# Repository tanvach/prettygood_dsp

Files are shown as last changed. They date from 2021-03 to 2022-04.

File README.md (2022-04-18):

# Prettygood DSP

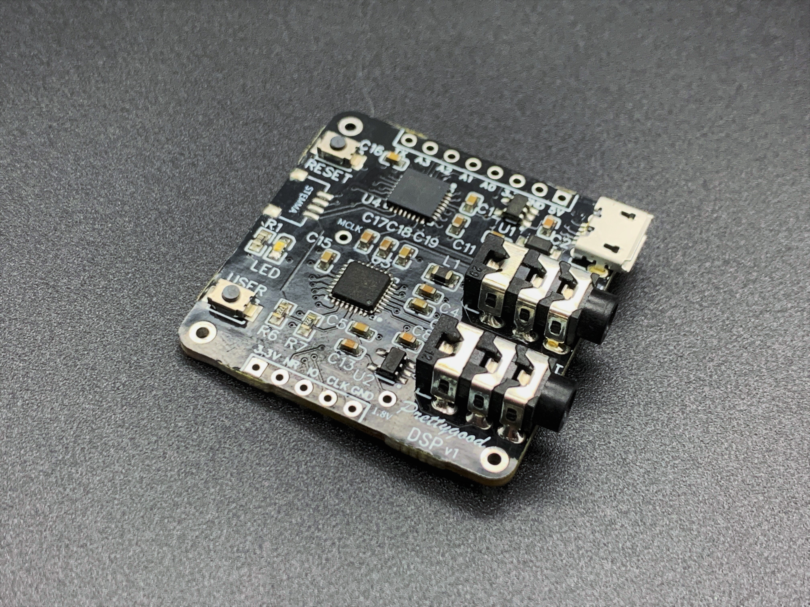
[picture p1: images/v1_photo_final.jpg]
board photo


A self contained, Arduino compatible board for applying audio DSP. The intended purpose is to equalize and apply bass boost to [BMR VR off ear headphones](https://prettygood3d.com/post/999028410814/quest-2-off-ear-bmr-v01), but can be adapted for any other light DSP tasks by SGTL5000 codec.

Supports:
-   7 band prarametric or 5 band graphic EQ.
-   AutoEQ profiles for 1000+ headphones and earbuds.
-   Psycho-acoustic bass boost to over come limited bass response of small headphone drivers.
-   Stereo surround expansion.
-   Automatic volume control.

Please see the SGTL5000 [documentation](https://www.pjrc.com/teensy/SGTL5000.pdf) for all DSP features. Credit to [Paul Stoffregen of PJRC.com](https://github.com/PaulStoffregen/Audio) for creating the Teensy Audio library (we're reusing a SGTL5000 component in the code).

TODO:
-   Make use of the USER button for switching between presets.

# Usage
- Plug in a USB power source. Anything from computer, phone, Quest/Quest 2 or some USB power bank (see below) should work.
- Plug in 3.5mm stereo jack from audio out to LINEIN.
- Plug your headphones into OUT.

NOTE: the OUT port is designed to drive headphones. It may not work as intended as an input into another audio device.

# WebUSB configurator
The latest version of the firmware allows you to config the DSP settings with Chrome browser through WebUSB.

To enter and use the WebUSB mode:
- Connect the board to your computer with a USB cable.
- Open a recent version of Chrome.
- Press and hold the *USER* button while pressing the *RESET* button.
- Release the *USER* button when the LED light turns off.
- Chrome should recorgnize the device as 'QT Py M0'.
- Click on the notification to go to the configuration page (https://tanvach.github.io/prettygood_dsp/).
- Click 'Connect' to pair and connect to the board (only needs to be done once).
- The LED light will turn on when WebUSB connection is established.

chrome notification

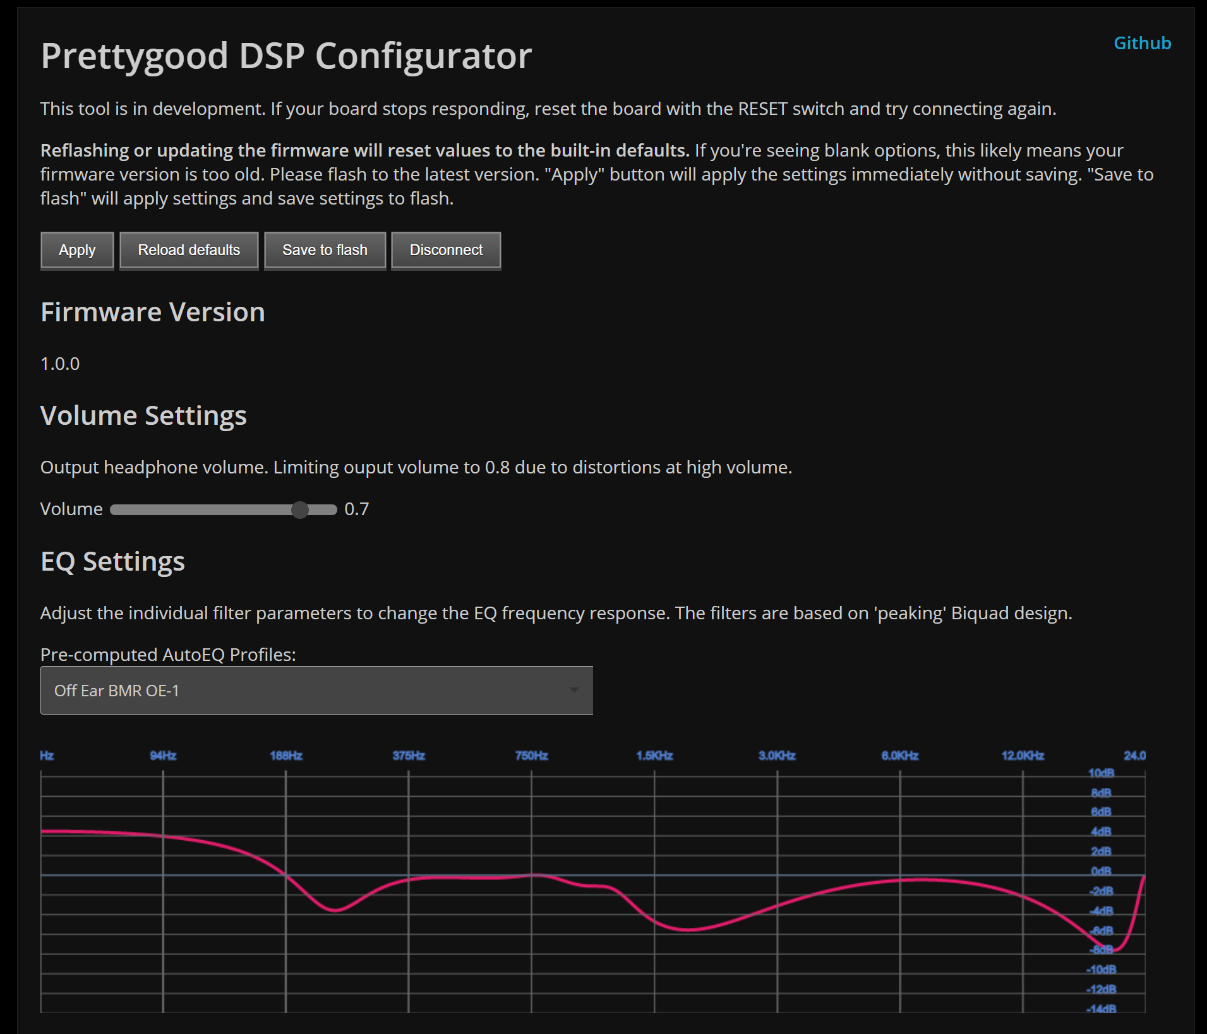
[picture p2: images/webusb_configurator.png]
webusb configurator


# USB Power Bank Compatibility
Most USB power banks will turn off when powering the board, since the current draw is too low.

- Some brands will allow 'low power draw' mode by holding the on button for few seconds (i.e. Xiaomi).
- A list of tested power banks that support low power draw https://www.candlepowerforums.com/vb/showthread.php?440476-USB-powerbank-WITHOUT-auto-off
- Use a USB splitter cable to power both the headset and DSP board (see below).
- Try using the 'Pulse USB Power' to periodically consume more power.

# Pulse USB Power
This feature will turn on the MCU DAC and periodically output max voltage to the A0 pin. This by itself consumes ~35mA of power. This is enough for some USB batteries to keep them awake. If not, you can conenct a short wire between A0 to GND to comsume even more power (~50mA). Adding this wire should be enough (tested with Anker branded batteries).

# USB Splitter Cable for Oculus Link
[This splitter cable](https://www.amazon.com/gp/product/B078MFCVLF/ref=ppx_yo_dt_b_asin_title_o00_s00?ie=UTF8&psc=1) is confirmed to work with Oculus Link and from power bank. It takes a Micro USB connection and split into USB-C (provides power and USB 2.0 data) and Micro USB (provides power only).

Alternatively, you can also [use this USB-C PD charging + USB-C headphone splitter](https://www.amazon.com/Splitter-HiMusic-Charging-Converter-Compatible/dp/B07MSLJ64X). The headphone port provides enough power to power the DSP. 

# Update firmware
The board firmare is updatable via USB.

- Connect the DSP board via USB and double clicking the RESET button. This triggers the boot loader mode.
- Check that the blue LED stays on and QTPY_BOOT drive is mounted on your desktop.
- Download 'firmware.uf2' file and copy it to the QTPY_BOOT drive. It should unmount automatically.
- The firmware update is complete. You can now disconnect the USB cable.

# Compile firmware
If you want to make changes to the firmware, you'd need to follow these steps.

*This board comes with a fail-safe bootloader mode, making it almost impossible to brick by updating the firmware through USB.*

## 1. Install Platform IO
You need to first install VSCode, then Platform IO by following [these instructions](https://platformio.org/install/ide?install=vscode).

## 2. Open in Platform IO
Download this repository using git clone command, or download and extract the zip file on your computer.

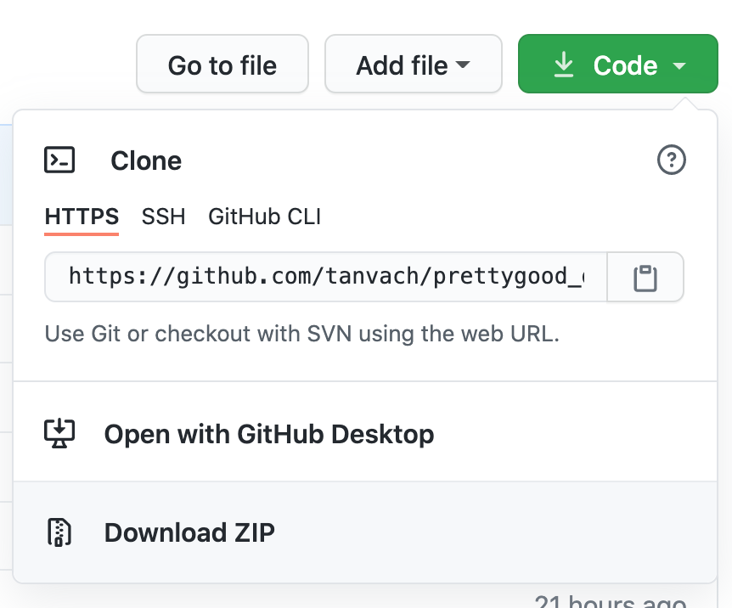
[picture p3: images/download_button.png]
download


In VSCode (with Platform IO installed), choose 'Open...' or 'Open Folder...' and select this repo's 'prettygood_dsp' folder.

## 3. Make changes and compile
Once you're happy making changes, select 'main.cpp' file and click the checkmark button at the bottom of VSCode to build the new firmware.

build

Platform IO will fetch all the dependencies automatically for you and compile the code. The file 'firmware.uf2' will be overwritten with the new version.

To upload the firmware, follow the 'Update firmware' section above.

## Dependencies
 - Adafruit Zero I2S
 - RTCZero
 - Adafruit TinyUSB Library
 - ArduinoJson
 - FlashStorage

# Board Design
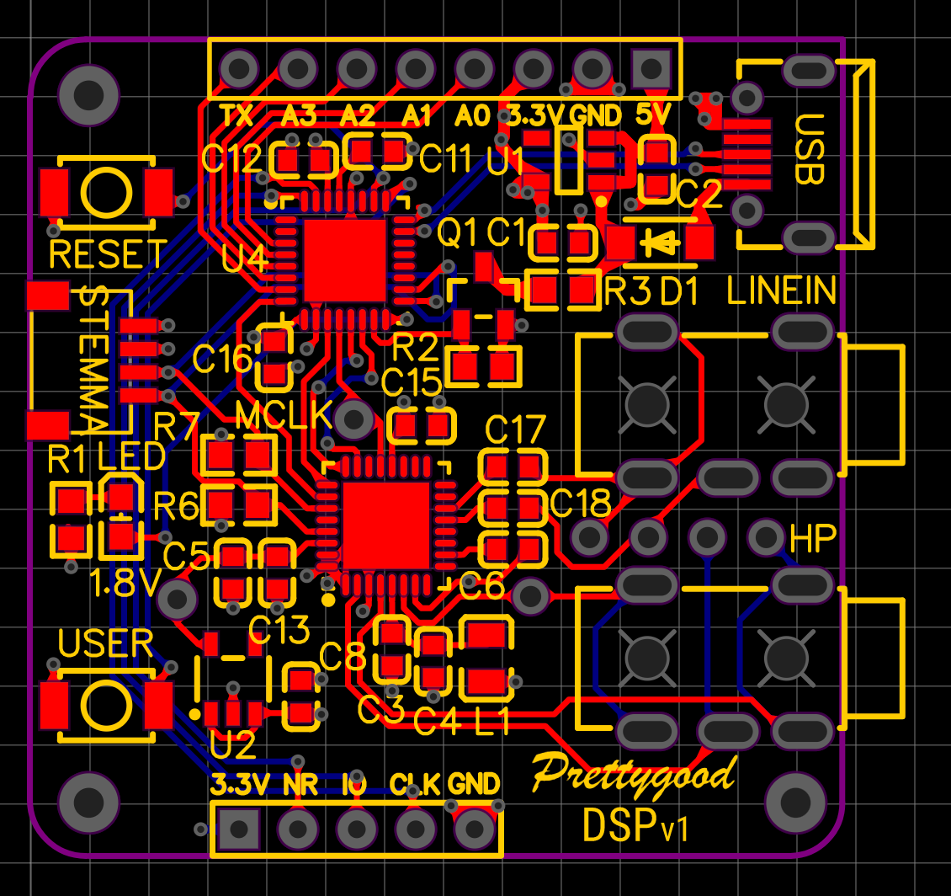
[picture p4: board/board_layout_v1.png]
Board Layout


The board is designed based on [Adafruit SAMD21 QtPy](https://learn.adafruit.com/adafruit-qt-py). The default bootloader is vanilla SAMD21 QtPy and can be download from [Adafruit SAMD UF2 repo](https://github.com/adafruit/uf2-samdx1/releases). The only difference is that we've replaced the NeoPixel with a blue LED.

The schematic can be found [here](board/schematic_v1.pdf).

The advantage of using this bootloader is that any projects that can run on SAMD21 boards (Aduino Zero, QtPy, Trinket M0, Feather M0) can theoretically run on Prettygood DSP.

One limitation - the I2S peripheral needs to be on to provide clock signals to the SGTL5000 codec. So the I2S/SPI pins are not available as GPIO. Otherwise the TX and A0-A3 pins are free and available.

# Contributing
Contributions are welcome!

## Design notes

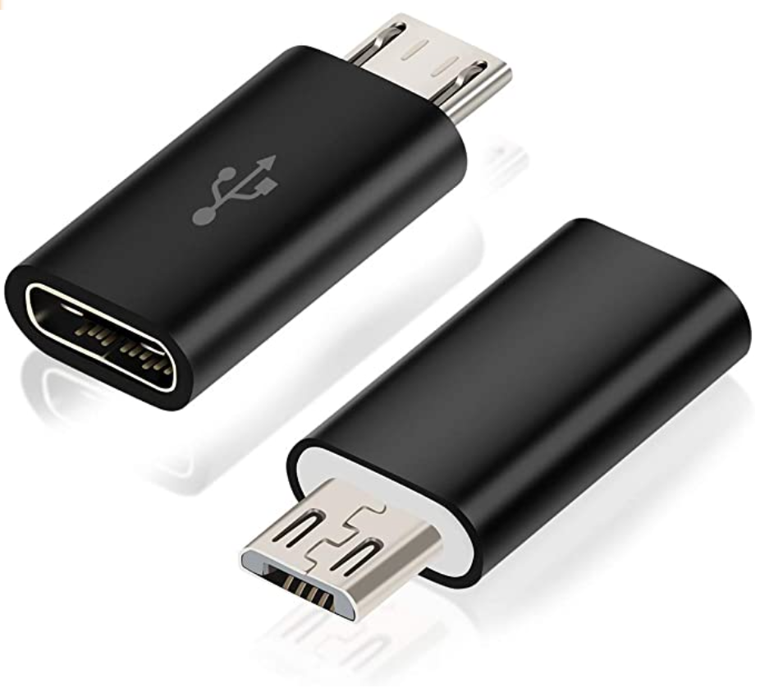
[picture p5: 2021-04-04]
images/usbc_to_micro.png

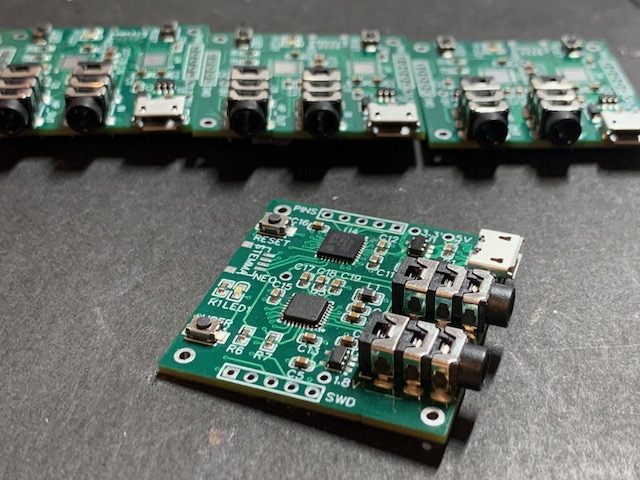
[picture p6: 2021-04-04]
images/v1_photo.jpeg

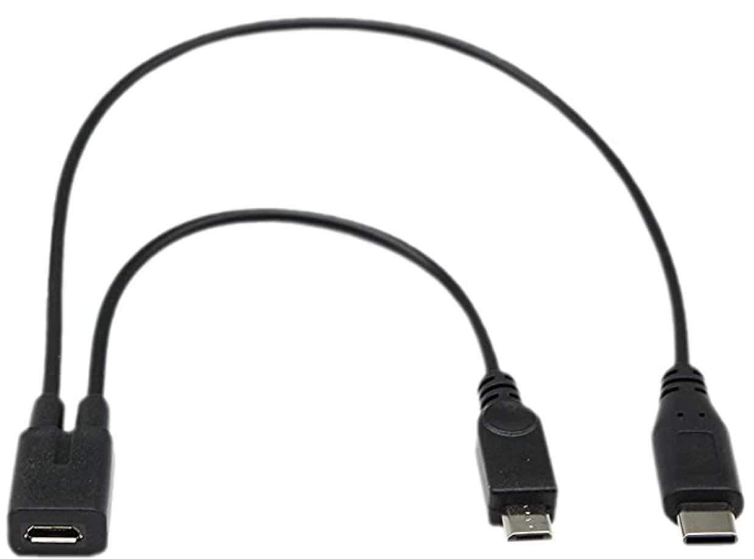
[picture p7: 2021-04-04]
images/micro_usb_splitter.png

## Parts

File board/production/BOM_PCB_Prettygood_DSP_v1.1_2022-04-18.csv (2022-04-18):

ID | Name | Designator | Footprint | Quantity | Manufacturer Part | Manufacturer | Supplier | Supplier Part | Price | Pins | 3DModel | Assembly Type | JLCPCB Part Class | JLCPCB SMD | LCSC Assembly | Paste Type | Contributor | Package Display | SMT Type | image | link | subpart_no
1 | B5819W | D1 | SOD-123_L2.8-W1.8-LS3.7-RD | 1 | B5819W | CJ | LCSC | C8598 | 0.039 | 2 | SOD-123_L2.8-W1.8-H1.4-LS3.7 | smtWeld |  | Yes | Yes | base | 官方封装库 |  | Basic | //image.lceda.cn/szlcsc/C8598.jpg | https://item.szlcsc.com/301422.html
2 | PJ-3930-8A | HP,IN | AUDIO-TH_PJ-3930-8A | 2 | PJ-3930-8A | HRO | LCSC | C145811 | 0.593 | 8 | AUDIO-TH_PJ-3930-8A |  | Extended Part |  |  |  | LCSC
3 | 150nF | C6 | C0603 | 1 | CL10B154KA8NNNC | SAMSUNG | LCSC | C21118 | 0.009 | 2 | C0603_L1.6-W0.8-H0.8 |  |  | Yes | Yes | expand | 立创EDA官方封装库 |  | Extend |  | https://item.szlcsc.com/362304.html
4 | 75 | R3 | R0603 | 1 | 0603WAF750JT5E | UniOhm | LCSC | C4275 | 0.001 | 2 | R0603_L1.6-W0.8-H0.8 |  |  | Yes | Yes | base | layout |  | Basic |  | https://item.szlcsc.com/137208.html
5 | 2N7002 | Q1 | SOT-23-3_L2.9-W1.3-P1.90-LS2.4-BR | 1 | 2N7002 | CJ | LCSC | C8545 | 0.023 | 3 | SOT-23-3P_L2.9-W1.3-H1.0-LS2.4-P0.95 |  |  | Yes | Yes | base | 立创EDA官方封装库 |  | Basic | //image.lceda.cn/szlcsc/C8545.jpg | https://item.szlcsc.com/9070.html
6 | 2.2K | R2,R6,R7 | R0603 | 3 | 0603WAF2201T5E | UniOhm | LCSC | C4190 | 0.001 | 2 | R0603_L1.6-W0.8-H0.8 | smtWeld |  | Yes | Yes | base | layout |  | Basic |  | https://item.szlcsc.com/137208.html
7 | NEO | MCLK | 1PIN | 1 | POINT |  |  | Do not populate |  | 1 |  |  |  |  |  |  | zydz
8 | 1.8V | 1.8V | 1PIN | 1 | POINT |  |  | Do not populate |  | 1 |  |  |  |  |  |  | zydz
9 | SGTL5000XNAA3 | U3 | QFN-32_L5.0-W5.0-P0.50-TL-EP3.7 | 1 | SGTL5000XNAA3 | NXP Semicon | LCSC | C511764 | 4.025 | 33 | QFN-32_L5.0-W5.0-H0.9-P0.50-TL-EP3.7 | smtWeld |  |  | Yes | expand | 官方封装库 |  | Extend |  | https://item.szlcsc.com/18002.html
10 | 2.2uF | C8,C5,C18,C17,C1,C2,C4 | C0603 | 7 | CL10A225KO8NNNC | SAMSUNG | LCSC | C23630 | 0.006 | 2 | C0603_L1.6-W0.8-H0.8 | smtWeld |  | Yes | Yes | base | 立创EDA官方封装库 |  | Basic |  | https://item.szlcsc.com/362304.html
11 | 600Ω | L1 | L0805 | 1 | CBW201209U601T | FH | LCSC | C21286 | 0.006 | 2 | L0805_L2.0-W1.6-H0.9 | smtWeld |  | Yes | Yes | expand | layout |  | Extend |  | https://item.szlcsc.com/344132.html
12 | ATSAMD21E18A-MU | U4 | QFN-32_L5.0-W5.0-P0.50-TL-EP | 1 | ATSAMD21E18A-MU | Microchip Tech | LCSC | C220692 | 2.795 | 33 | QFN-32_L5.0-W5.0-H1.0-P0.50-TL-EP | smtWeld |  | Yes | Yes | expand | 官方封装库 |  | Extend |  | https://item.szlcsc.com/18002.html
13 | AP2112K-3.3TRG1 | U1 | SOT-25-5_L3.0-W1.8-P0.95-LS3.0-BR | 1 | AP2112K-3.3TRG1 | DIODES | LCSC | C51118 | 1.49 | 5 | SOT-25-5_L3.0-W1.6-H1.3-LS2.8-P0.95 | smtWeld |  | Yes |  | recommend | LCSC |  | Extend |  | https://item.szlcsc.com/70677.html
14 | SWD | SWD | 1X5PIN | 1 |  |  |  | Do not populate |  | 5 |  |  |  |  |  |  | cmacarthur | No
15 | Pad | P1,P2,P3 | PAD | 3 |  |  |  | Do not populate |  | 1 |  |  |  |  |  |  | ericriss102 | No
16 | STEMMA_I2C_QT | STEMMA | JST_SH4 | 1 |  |  |  | Do not populate |  | 6 |  |  |  |  |  |  | wolf3x | No |  |  |  | 1
17 | ME6212C18M5G | U2 | SOT-23-5_L3.0-W1.7-P0.95-LS2.8-BL | 1 | ME6212C18M5G | Nanjing Micro One Elec | LCSC | C236669 | 0.05 | 5 | SOT-23-5_L2.9-W1.6-H1.1-LS2.8-P0.95 | smtWeld |  | Yes | Yes | expand | LCSC |  | Extend |  | https://item.szlcsc.com/236104.html
18 | 100nF | C3,C12,C13,C15,C16 | C0603 | 5 | CC0603KRX7R9BB104 | YAGEO | LCSC | C14663 | 0.002 | 2 | C0603_L1.6-W0.8-H0.8 | smtWeld |  | Yes | Yes | base | 立创EDA官方封装库 |  | Basic |  | https://item.szlcsc.com/362304.html
19 | 1uF | C11 | C0603 | 1 | CL10A105KB8NNNC | SAMSUNG | LCSC | C15849 | 0.005 | 2 | C0603_L1.6-W0.8-H0.8 | smtWeld |  | Yes | Yes | base | 立创EDA官方封装库 |  | Basic |  | https://item.szlcsc.com/362304.html
20 | 1K | R1 | R0603 | 1 | 0603WAF1001T5E | UniOhm | LCSC | C21190 | 0.001 | 2 | R0603_L1.6-W0.8-H0.8 | smtWeld |  | Yes | Yes | base | layout |  | Basic |  | https://item.szlcsc.com/137208.html
21 | MICROXNJ | USB | MICRO-USB-SMD_MICROXNJ | 1 | MicroXNJ | SHOU HAN | LCSC | C404969 | 0.046 | 9 | MICRO-USB-SMD_105017-0001 | smtWeld |  |  |  | expand | LCSC |  |  |  | https://item.szlcsc.com/392534.html
22 | 1x8 | PINS | HDR-8X1/2.54 | 1 |  |  |  | Do not populate |  | 8 |  |  |  |  |  |  |  | No
23 | TS-1088-AR02016 | RESET,USER | SW-SMD_L4.0-W2.9-LS5.0 | 2 | TS-1088-AR02016 | XUNPU | LCSC | C720477 | 0.049 | 2 |  | smtWeld |  |  | Yes | expand | LCSC |  | Extend |  | https://item.szlcsc.com/330471.html
24 | 19-217/BHC-ZL1M2RY/3T | LED | LED0603-R-RD | 1 | 19-217/BHC-ZL1M2RY/3T | EVERLIGHT | LCSC | C72041 | 0.019 | 2 | LED0603_Green | smtWeld |  | Yes | Yes | base | 官方封装库 |  | Basic | //image.lceda.cn/szlcsc/C72041.jpg | https://lcsc.com/product-detail/Light-Emitting-Diodes-LED_Hubei-KENTO-Elec-0603-Green_C12624.html

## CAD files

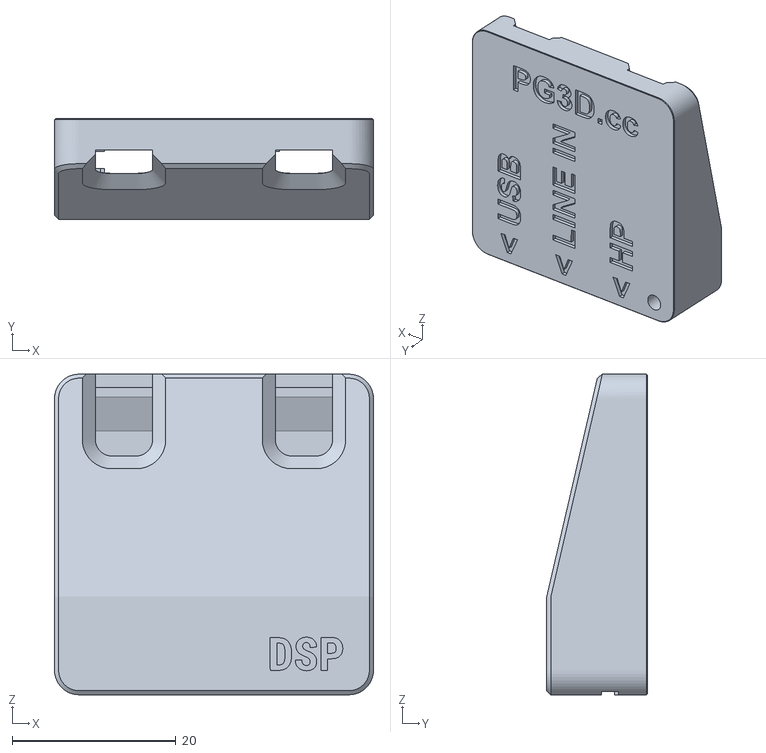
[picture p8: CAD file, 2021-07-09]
board/prettygood_dsp_case.stl
39.0 x 12.3 x 39.2

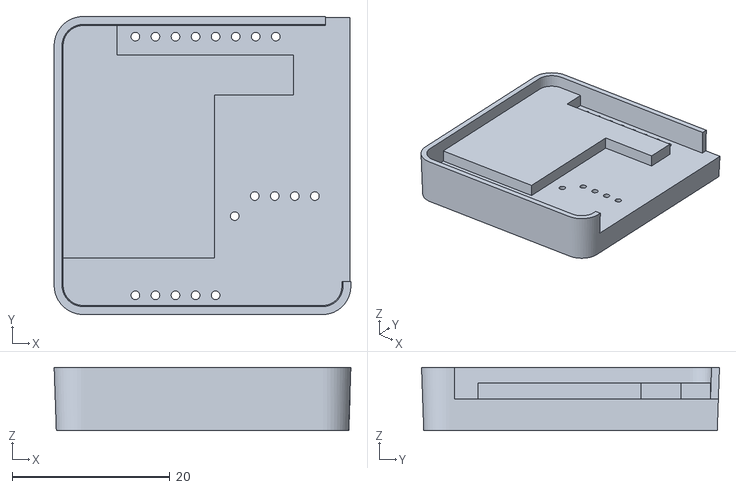
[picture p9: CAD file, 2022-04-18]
programmer/v1.1 test jig PCB.stl
37.6 x 37.7 x 8.00

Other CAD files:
case/Prettygood DSP.step
case/prettygood_dsp_case.3mf
case/Prettygood DSP Case.f3d

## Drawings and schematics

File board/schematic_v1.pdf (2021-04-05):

## Switches

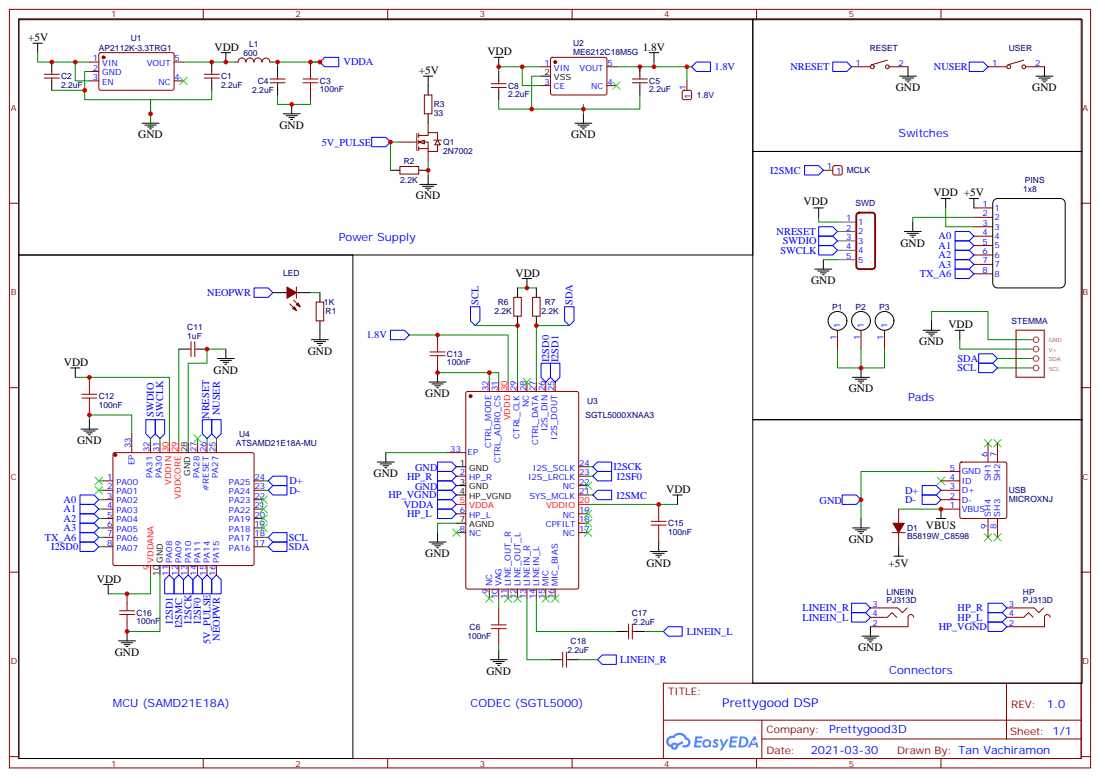
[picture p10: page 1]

NC 17 CPFILT 18 NC 19 VDDIO 20 SYS_MCLK 21 NC 22 I2S_LRCLK 23 I2S_SCLK 24 I2S_DOUT 25 I2S_DIN ²⁶ CTRL_DATA 27 NC 28 CTRL_CLK 29

Drawn By: Tan Vachiramon

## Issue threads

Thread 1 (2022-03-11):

Etsy store links dead

AGSPhoenix, 2022-03-11:
The various links to your store in this repo and on your site are dead, with no useful explanation from them as to why. Are you still selling these kits?

If not, any plans to release the STLs and Gerbers so we can make our own?

tanvach, 2022-03-11:
Hello - we're closing our store and will release the files sometime this month.

tanvach, 2022-04-18:
Updated to remove the Etsy store link. Added PCB files (gerber + easyeda json), case 3d model files, and programmer files.

Closed 2022-04-18.

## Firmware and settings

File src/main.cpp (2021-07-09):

/* Prettygood3D Over Ear (OE-1) DSP board
 * Copyright (c) 2021, Pithawat Vachiramon, prettygood3d@gmail.com
 *
 * Development of this code was funded by Prettygood3D.com. Please support
 * Prettygood3D's efforts to develop open source software by purchasing the
 * DSP board and other Prettygood3D products.
 *
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
 * THE SOFTWARE IS PROVIDED "AS IS", WITHOUT WARRANTY OF ANY KIND, EXPRESS OR
 * IMPLIED, INCLUDING BUT NOT LIMITED TO THE WARRANTIES OF MERCHANTABILITY,
 * FITNESS FOR A PARTICULAR PURPOSE AND NONINFRINGEMENT. IN NO EVENT SHALL THE
 * AUTHORS OR COPYRIGHT HOLDERS BE LIABLE FOR ANY CLAIM, DAMAGES OR OTHER
 * LIABILITY, WHETHER IN AN ACTION OF CONTRACT, TORT OR OTHERWISE, ARISING FROM,
 * OUT OF OR IN CONNECTION WITH THE SOFTWARE OR THE USE OR OTHER DEALINGS IN
 * THE SOFTWARE.
 */

#define VERSION "1.0.1"

#include <Arduino.h>
#include <Adafruit_ZeroI2S.h>
#include <RTCZero.h>
#include <Adafruit_TinyUSB.h>
#include "control_sgtl5000.h"
#include "config.h"

// Pins
#define LED_PIN 12
#define USER_BUTTON_PIN 13
#define POWER_PULSE_PIN 21
#define I2S_RX_PIN 17
#define I2S_TX_PIN PIN_I2S_SD

// Audio
#define SAMPLERATE_HZ 44100
#define BITWIDTH I2S_16_BIT
AudioControlSGTL5000 audioShield;
Adafruit_ZeroI2S i2s = Adafruit_ZeroI2S(PIN_I2S_FS, PIN_I2S_SCK, I2S_RX_PIN, I2S_TX_PIN);

// Stand by and alarms
RTCZero rtc;

// USB WebUSB object
Adafruit_USBD_WebUSB usb_web;
WEBUSB_URL_DEF(landingPage, 1 /*https*/, "tanvach.github.io/prettygood_dsp/index.html");

// Shared variables
volatile boolean active = true;
volatile boolean user_button_pushed = false;
volatile boolean power_pulse = false;

void SetupI2S() {
  
  if (!i2s.begin(BITWIDTH, SAMPLERATE_HZ)) {
    while (1);            
  }

  // // Change I2S clocks to output reasonable frequency for SGTL5000's PLL
  // // For SAMD21, Adafruit_ZeroI2S divides DFLL48M clock equally for MCLK and BCLK
  // // Need to change so that MCLK = 8Mhz
  // GCLK->GENDIV.reg = GCLK_GENDIV_DIV(6) |             // Divide by 4
  //                    GCLK_GENDIV_ID(I2S_GCLK_ID_0);   // Divide the clock for I2S
  // while (GCLK->STATUS.bit.SYNCBUSY);

  // Change I2S clocks to output reasonable frequency for SGTL5000's PLL
  // Override and use OSC8M Oscillator because it's lower power and less noisy
  while (GCLK->STATUS.bit.SYNCBUSY);
  GCLK->GENDIV.bit.ID = I2S_CLOCK_GENERATOR;
  GCLK->GENDIV.bit.DIV = 1;
  while (GCLK->STATUS.bit.SYNCBUSY);
  GCLK->GENCTRL.bit.ID = I2S_CLOCK_GENERATOR;
  GCLK->GENCTRL.bit.SRC = GCLK_GENCTRL_SRC_OSC8M_Val;
  GCLK->GENCTRL.bit.IDC = 1;
  GCLK->GENCTRL.bit.GENEN = 1;
  while (GCLK->STATUS.bit.SYNCBUSY);

  // Enable MCLK on Pin PA09
  I2S->CLKCTRL[0].bit.MCKEN = 1;
  PORT->Group[PORTA].PINCFG[9].bit.PMUXEN = 1;
  PORT->Group[PORTA].PMUX[9 >> 1].reg |= PORT_PMUX_PMUXO_G; 

  // Disable BCLK and FS since we're using SGTL5000 as master
  // TODO: Change this so receiving I2S works
  PORT->Group[PORTA].PINCFG[10].bit.PMUXEN = 0;
  PORT->Group[PORTA].PINCFG[11].bit.PMUXEN = 0;

  // Configure the regulator and clocks to run in standby mode
  SYSCTRL->VREG.bit.RUNSTDBY = 1;
  SYSCTRL->DFLLCTRL.bit.RUNSTDBY = 1;
  SYSCTRL->OSC8M.bit.RUNSTDBY = 1;
  GCLK->GENCTRL.bit.RUNSTDBY = 1;

  // Enable I2S to receive mode
  i2s.enableRx();
}

void SetupSGTL5000() {

  audioShield.muteHeadphone();
  audioShield.inputSelect(AUDIO_INPUT_LINEIN);
  audioShield.enhanceBassDisable();
  audioShield.autoVolumeDisable();

  // Psycho-acoutic bass boost
  if (config_doc["enhance_bass"]) {
    float lr_vol = config_doc["enhance_bass_lr_vol"];
    float bass_vol = config_doc["enhance_bass_bass_vol"];
    uint8_t high_pass = config_doc["enhance_bass_high_pass"];
    uint8_t cutoff = config_doc["enhance_bass_cutoff"];
    audioShield.enhanceBassEnable();
    audioShield.enhanceBass(lr_vol, bass_vol, high_pass, cutoff);
  }

    // Auto volume
  if (config_doc["auto_volume"]) {
    uint8_t maxGain = config_doc["auto_volume_max_gain"];
    uint8_t lbiResponse = config_doc["auto_volume_lbi_response"];
    uint8_t hardLimit = config_doc["auto_volume_hard_limit"];
    float threshold = config_doc["auto_volume_threshold"];
    float attack = config_doc["auto_volume_attack"];
    float decay = config_doc["auto_volume_decay"];
    audioShield.autoVolumeEnable();
    audioShield.autoVolumeControl(maxGain, lbiResponse, hardLimit, threshold, attack, decay);
  }

  // Set up EQ filters
  uint8_t filter_type = config_doc["filter_type"];
  uint8_t filter_count = config_doc["filter_count"];
  audioShield.eqSelect(filter_type);
  audioShield.eqFilterCount(filter_count);

  // Parametric EQ
  if (filter_type == 1) {

    int updateFilter[5];    

    for (uint8_t i = 0; i < filter_count; i++) {
      // Usage: calcBiquad(filtertype, fC, dB_Gain, Q, quantization_unit, fS, *coef)
      // quantization_unit is fixed at 524288 for SGTL5000
      float filter_fc = config_doc["filter_fc"][i];
      float filter_db = config_doc["filter_db"][i];
      float filter_q = config_doc["filter_q"][i];
      // Serial.print("Biquad filter ");
      // Serial.print(i);
      // Serial.print(" with fc:");
      // Serial.print(filter_fc);
      // Serial.print(" gain:");
      // Serial.print(filter_db);
      // Serial.print(" q:");
      // Serial.print(filter_q);
      // Serial.println();

      calcBiquad(
        FILTER_PARAEQ, 
        filter_fc, 
        filter_db, 
        filter_q, 
        524288, 
        SAMPLERATE_HZ, 
        updateFilter
      );
      audioShield.eqFilter(i, updateFilter);
    }
  }

  // High pass filter adds noise for some reason. We don't need it.
  audioShield.adcHighPassFilterDisable();

  // Enable output
  float volume = config_doc["volume"];
  audioShield.volume(volume);
  audioShield.unmuteHeadphone();
}


// WebUSB
void SendConfigJSON() {
  serializeJsonPretty(config_doc, usb_web);
  usb_web.println("\n");
  usb_web.println("<<EOF>>");
  delay(100);
}

// Call backs
void user_button_isr() {
  user_button_pushed = true;
}

void line_state_callback(bool connected)
{
  digitalWrite(LED_PIN, connected);
  // Send config JSON to browser
  if ( connected ) SendConfigJSON();
}

void alarm_callback() {
  power_pulse = true;
}

// Power pulse regular alarm
void SetAlarmThenSleep() {
  bool keep_usb_battery_on = config_doc["keep_usb_battery_on"];
  int total_sec = config_doc["keep_usb_battery_on_pulse_period_sec"];
  if (keep_usb_battery_on & (total_sec > 0) & (total_sec < 3600)) {
    uint8_t seconds = total_sec % 60;
    uint8_t minutes = total_sec / 60;
    rtc.setTime(0, 0, 0);
    rtc.setDate(1, 1, 21);
    rtc.setAlarmTime(0, minutes, seconds);
    rtc.enableAlarm(rtc.MATCH_HHMMSS);
    rtc.attachInterrupt(alarm_callback);
  }
  rtc.standbyMode();
}

bool isUSBConnected() {
  // Detect USB connection by checking if there's a change in USB frame number
  uint16_t f = USB->DEVICE.FNUM.bit.FNUM;
  delay(3);
  return f != USB->DEVICE.FNUM.bit.FNUM;
}

// Pulse USB power by wasting current
void PowerPulse(bool state) {
  if (state) {
    pinMode(A0, OUTPUT);
    analogWrite(A0, 1023);
  } else {
    digitalWrite(A0, LOW);
    pinMode(A0, INPUT);
  }
  digitalWrite(POWER_PULSE_PIN, state);
  if (config_doc["keep_usb_battery_on_led"]) digitalWrite(LED_PIN, state);
}

// Begin usual Arduino code

void setup() {
  Serial.begin(115200);

  // delay(2000);
  LoadConfig();
  serializeJsonPretty(config_doc, Serial);
  Serial.println();
  // delay(1000);

  // Set up I2S clocks
  SetupI2S();
  delay(10);

  // Enable as Master, input clock 8Mhz
  audioShield.enable(8000000);
  // Set up SGTL5000
  SetupSGTL5000();

  // Turn LED off
  pinMode(LED_PIN, OUTPUT);
  digitalWrite(LED_PIN, LOW);

  // Enable USER button (active low)
  pinMode(USER_BUTTON_PIN, INPUT_PULLUP);
  attachInterrupt(USER_BUTTON_PIN, user_button_isr, CHANGE);

  // USB power pulse (v1.1 board and above only)
  pinMode(POWER_PULSE_PIN, OUTPUT);
  analogWriteResolution(10);
  
  // Enter stand by to save power if USER button is not held down while booting
  if (digitalRead(USER_BUTTON_PIN)) {
    active = false;
    rtc.begin();
    // Allow USB to make connection first
    delay(1000);
    SetAlarmThenSleep();
  } else {
    // If USER button is pressed then set up WebUSB for configuration
    active = true;
    usb_web.setLandingPage(&landingPage);
    usb_web.setLineStateCallback(line_state_callback);
    usb_web.setStringDescriptor("Prettygood DSP WebUSB");
    usb_web.begin();
    // Allow USB to make connection first
    delay(1000);
  }
}

void loop() {

  // Process user button push event
  if (user_button_pushed) {
    // Do nothing
    user_button_pushed = false;
  }

  // Process power pulse alarm event
  if (power_pulse) {
    power_pulse = false;
    // Only pulse if not real USB connection (i.e. USB powerbank)
    if (!isUSBConnected()) {
      uint16_t pulse_duration_ms = config_doc["keep_usb_battery_on_pulse_duration_msec"];
      // Max pulse = 2s
      pulse_duration_ms = min(pulse_duration_ms, 2000);
      // Pulse
      PowerPulse(HIGH);
      delay(pulse_duration_ms);
      PowerPulse(LOW);
    }
  }

  if (active) {

    // WebUSB
    if (usb_web.available()) {

      DynamicJsonDocument received_doc(JSON_DOC_SIZE);
      deserializeJson(received_doc, usb_web);

      // Check that the config is valid
      // TODO: Better check
      if ((received_doc["volume"] >= 0.0) & (received_doc["volume"] <= 1.0)) {
        config_doc = received_doc;
        SetupSGTL5000();
        SendConfigJSON();
      }

      // Reload defaults config
      if (received_doc["reload_defaults"]) {
        LoadConfig(true);
        SetupSGTL5000();
        SendConfigJSON();
      }

      // Save to flash 
      if (received_doc["save_to_flash"]) {
        SaveConfig();
        SendConfigJSON();
      }
      
    }

  } else {
    // Stand by if not booted in active mode
    SetAlarmThenSleep();
  }
}

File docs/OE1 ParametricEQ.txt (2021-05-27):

Preamp: -4.6 dB
Filter 1: ON PK Fc 59 Hz Gain 6.6 dB Q 0.17
Filter 2: ON PK Fc 243 Hz Gain -6.4 dB Q 1.71
Filter 3: ON PK Fc 811 Hz Gain 2.2 dB Q 1.90
Filter 4: ON PK Fc 1189 Hz Gain 3.3 dB Q 2.45
Filter 5: ON PK Fc 1645 Hz Gain -7.2 dB Q 0.64
Filter 6: ON PK Fc 6243 Hz Gain 1.4 dB Q 0.30
Filter 7: ON PK Fc 19864 Hz Gain -7.8 dB Q 0.38

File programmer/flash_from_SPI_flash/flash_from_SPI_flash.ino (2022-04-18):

#include "Adafruit_DAP.h"
#include <SdFat.h>
#include <Adafruit_SPIFlash.h>

#define FILENAME "fw.bin"

#define SWDIO 12
#define SWCLK 11
#define SWRST 9

const int BUFSIZE = Adafruit_DAP_SAM::PAGESIZE;
uint8_t buf[BUFSIZE];

//create a DAP for programming Atmel SAM devices
Adafruit_DAP_SAM dap;

// Configuration of the flash chip pins and flash fatfs object.
// You don't normally need to change these if using a Feather/Metro
// M0 express board.
#if defined(__SAMD51__) || defined(NRF52840_XXAA)
  Adafruit_FlashTransport_QSPI flashTransport(PIN_QSPI_SCK, PIN_QSPI_CS, PIN_QSPI_IO0, PIN_QSPI_IO1, PIN_QSPI_IO2, PIN_QSPI_IO3);
#else
  #if (SPI_INTERFACES_COUNT == 1 || defined(ADAFRUIT_CIRCUITPLAYGROUND_M0))
    Adafruit_FlashTransport_SPI flashTransport(SS, &SPI);
  #else
    Adafruit_FlashTransport_SPI flashTransport(SS1, &SPI1);
  #endif
#endif

Adafruit_SPIFlash flash(&flashTransport);
// file system object from SdFat
FatFileSystem fatfs;

// Function called when there's an SWD error
void error(const char *text) {
  Serial.println(text);
  while (1);
}


void setup() {
  pinMode(LED_BUILTIN, OUTPUT);
  Serial.begin(115200);
//  while(!Serial) {
//    delay(1);         // will pause the chip until it opens serial console
//  }

  dap.begin(SWCLK, SWDIO, SWRST, &error);
  
  // Initialize flash library and check its chip ID.
  if (!flash.begin()) {
    Serial.println("Error, failed to initialize flash chip!");
    while(1);
  }
  Serial.print("Flash chip JEDEC ID: 0x"); Serial.println(flash.getJEDECID(), HEX);

  // First call begin to mount the filesystem.  Check that it returns true
  // to make sure the filesystem was mounted.
  if (!fatfs.begin(&flash)) {
    Serial.println("Failed to mount filesystem!");
    Serial.println("Was CircuitPython loaded on the board first to create the filesystem?");
    while(1);
  }
  Serial.println("Mounted filesystem!");

  File dataFile = fatfs.open(FILENAME, FILE_READ);
  if(!dataFile){
     error("Couldn't open file");
  }
  
  Serial.println("Connecting...");
  if ( !dap.targetConnect() ) {
    error(dap.error_message);
  }

  char debuggername[100];
  dap.dap_get_debugger_info(debuggername);
  Serial.print(debuggername); Serial.print("\n\r");

  uint32_t dsu_did;
  if (! dap.select(&dsu_did)) {
    Serial.print("Unknown device found 0x"); Serial.print(dsu_did, HEX);
    error("Unknown device found");
  }
  Serial.print("Found Target: ");
  Serial.print(dap.target_device.name);
  Serial.print("\tFlash size: ");
  Serial.print(dap.target_device.flash_size);
  Serial.print("\tFlash pages: ");
  Serial.println(dap.target_device.n_pages);

  /* Example of how to read and set fuses
  Serial.print("Fuses... ");
  dap.fuseRead(); //MUST READ FUSES BEFORE SETTING OR WRITING ANY
  dap._USER_ROW.WDT_Period = 0x0A;
  dap.fuseWrite();
  Serial.println(" done.");
  */

  Serial.print("Erasing... ");
  dap.erase();
  Serial.println(" done.");
  
  Serial.print("Programming... ");
  unsigned long t = millis();
  uint32_t addr = dap.program_start();

  while (dataFile.available()) {
      memset(buf, BUFSIZE, 0xFF);  // empty it out
      dataFile.read(buf, BUFSIZE);
      dap.programBlock(addr, buf);
      addr += BUFSIZE;
  }
  dataFile.close();
  Serial.println(millis() - t);
  Serial.println("\nDone!");
  dap.dap_set_clock(50);

  dap.deselect();
  dap.dap_disconnect();
}

void loop() {
  //blink led on the host to show we're done
  digitalWrite(LED_BUILTIN, HIGH);
  delay(500);
  digitalWrite(LED_BUILTIN, LOW);
  delay(500);
}

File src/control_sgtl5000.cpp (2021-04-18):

/* Audio Library for Teensy 3.X
 * Copyright (c) 2014, Paul Stoffregen, paul@pjrc.com
 *
 * Development of this audio library was funded by PJRC.COM, LLC by sales of
 * Teensy and Audio Adaptor boards.  Please support PJRC's efforts to develop
 * open source software by purchasing Teensy or other PJRC products.
 *
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
 * THE SOFTWARE IS PROVIDED "AS IS", WITHOUT WARRANTY OF ANY KIND, EXPRESS OR
 * IMPLIED, INCLUDING BUT NOT LIMITED TO THE WARRANTIES OF MERCHANTABILITY,
 * FITNESS FOR A PARTICULAR PURPOSE AND NONINFRINGEMENT. IN NO EVENT SHALL THE
 * AUTHORS OR COPYRIGHT HOLDERS BE LIABLE FOR ANY CLAIM, DAMAGES OR OTHER
 * LIABILITY, WHETHER IN AN ACTION OF CONTRACT, TORT OR OTHERWISE, ARISING FROM,
 * OUT OF OR IN CONNECTION WITH THE SOFTWARE OR THE USE OR OTHER DEALINGS IN
 * THE SOFTWARE.
 */

#include <Arduino.h>
#include "control_sgtl5000.h"
#include "Wire.h"

#define CHIP_ID				0x0000
// 15:8 PARTID		0xA0 - 8 bit identifier for SGTL5000
// 7:0  REVID		0x00 - revision number for SGTL5000.

#define CHIP_DIG_POWER			0x0002
// 6	ADC_POWERUP	1=Enable, 0=disable the ADC block, both digital & analog,
// 5	DAC_POWERUP	1=Enable, 0=disable the DAC block, both analog and digital
// 4	DAP_POWERUP	1=Enable, 0=disable the DAP block
// 1	I2S_OUT_POWERUP	1=Enable, 0=disable the I2S data output
// 0	I2S_IN_POWERUP	1=Enable, 0=disable the I2S data input

#define CHIP_CLK_CTRL			0x0004
// 5:4	RATE_MODE	Sets the sample rate mode. MCLK_FREQ is still specified
//			relative to the rate in SYS_FS
//				0x0 = SYS_FS specifies the rate
//				0x1 = Rate is 1/2 of the SYS_FS rate
//				0x2 = Rate is 1/4 of the SYS_FS rate
//				0x3 = Rate is 1/6 of the SYS_FS rate
// 3:2	SYS_FS		Sets the internal system sample rate (default=2)
//				0x0 = 32 kHz
//				0x1 = 44.1 kHz
//				0x2 = 48 kHz
//				0x3 = 96 kHz
// 1:0	MCLK_FREQ	Identifies incoming SYS_MCLK frequency and if the PLL should be used
//				0x0 = 256*Fs
//				0x1 = 384*Fs
//				0x2 = 512*Fs
//				0x3 = Use PLL
//				The 0x3 (Use PLL) setting must be used if the SYS_MCLK is not
//				a standard multiple of Fs (256, 384, or 512). This setting can
//				also be used if SYS_MCLK is a standard multiple of Fs.
//				Before this field is set to 0x3 (Use PLL), the PLL must be
//				powered up by setting CHIP_ANA_POWER->PLL_POWERUP and
//				CHIP_ANA_POWER->VCOAMP_POWERUP.  Also, the PLL dividers must
//				be calculated based on the external MCLK rate and
//				CHIP_PLL_CTRL register must be set (see CHIP_PLL_CTRL register
//				description details on how to calculate the divisors).

#define CHIP_I2S_CTRL			0x0006
// 8	SCLKFREQ	Sets frequency of I2S_SCLK when in master mode (MS=1). When in slave
//			mode (MS=0), this field must be set appropriately to match SCLK input
//			rate.
//				0x0 = 64Fs
//				0x1 = 32Fs - Not supported for RJ mode (I2S_MODE = 1)
// 7	MS		Configures master or slave of I2S_LRCLK and I2S_SCLK.
//				0x0 = Slave: I2S_LRCLK an I2S_SCLK are inputs
//				0x1 = Master: I2S_LRCLK and I2S_SCLK are outputs
//				NOTE: If the PLL is used (CHIP_CLK_CTRL->MCLK_FREQ==0x3),
//				the SGTL5000 must be a master of the I2S port (MS==1)
// 6	SCLK_INV	Sets the edge that data (input and output) is clocked in on for I2S_SCLK
//				0x0 = data is valid on rising edge of I2S_SCLK
//				0x1 = data is valid on falling edge of I2S_SCLK
// 5:4	DLEN		I2S data length (default=1)
//				0x0 = 32 bits (only valid when SCLKFREQ=0),
//					not valid for Right Justified Mode
//				0x1 = 24 bits (only valid when SCLKFREQ=0)
//				0x2 = 20 bits
//				0x3 = 16 bits
// 3:2	I2S_MODE	Sets the mode for the I2S port
//				0x0 = I2S mode or Left Justified (Use LRALIGN to select)
//				0x1 = Right Justified Mode
//				0x2 = PCM Format A/B
//				0x3 = RESERVED
// 1	LRALIGN		I2S_LRCLK Alignment to data word. Not used for Right Justified mode
//				0x0 = Data word starts 1 I2S_SCLK delay after I2S_LRCLK
//					transition (I2S format, PCM format A)
//				0x1 = Data word starts after I2S_LRCLK transition (left
//					justified format, PCM format B)
// 0	LRPOL		I2S_LRCLK Polarity when data is presented.
//				0x0 = I2S_LRCLK = 0 - Left, 1 - Right
//				1x0 = I2S_LRCLK = 0 - Right, 1 - Left
//				The left subframe should be presented first regardless of
//				the setting of LRPOL.

#define CHIP_SSS_CTRL			0x000A
// 14	DAP_MIX_LRSWAP	DAP Mixer Input Swap
//				0x0 = Normal Operation
//				0x1 = Left and Right channels for the DAP MIXER Input are swapped.
// 13	DAP_LRSWAP	DAP Mixer Input Swap
//				0x0 = Normal Operation
//				0x1 = Left and Right channels for the DAP Input are swapped
// 12	DAC_LRSWAP	DAC Input Swap
//				0x0 = Normal Operation
//				0x1 = Left and Right channels for the DAC are swapped
// 10	I2S_LRSWAP	I2S_DOUT Swap
//				0x0 = Normal Operation
//				0x1 = Left and Right channels for the I2S_DOUT are swapped
// 9:8	DAP_MIX_SELECT	Select data source for DAP mixer
//				0x0 = ADC
//				0x1 = I2S_IN
//				0x2 = Reserved
//				0x3 = Reserved
// 7:6	DAP_SELECT	Select data source for DAP
//				0x0 = ADC
//				0x1 = I2S_IN
//				0x2 = Reserved
//				0x3 = Reserved
// 5:4	DAC_SELECT	Select data source for DAC (default=1)
//				0x0 = ADC
//				0x1 = I2S_IN
//				0x2 = Reserved
//				0x3 = DAP
// 1:0	I2S_SELECT	Select data source for I2S_DOUT
//				0x0 = ADC
//				0x1 = I2S_IN
//				0x2 = Reserved
//				0x3 = DAP

#define CHIP_ADCDAC_CTRL		0x000E
// 13	VOL_BUSY_DAC_RIGHT Volume Busy DAC Right
//				0x0 = Ready
//				0x1 = Busy - This indicates the channel has not reached its
//					programmed volume/mute level
// 12	VOL_BUSY_DAC_LEFT  Volume Busy DAC Left
//				0x0 = Ready
//				0x1 = Busy - This indicates the channel has not reached its
//					programmed volume/mute level
// 9	VOL_RAMP_EN	Volume Ramp Enable (default=1)
//				0x0 = Disables volume ramp. New volume settings take immediate
//					effect without a ramp
//				0x1 = Enables volume ramp
//				This field affects DAC_VOL. The volume ramp effects both
//				volume settings and mute When set to 1 a soft mute is enabled.
// 8	VOL_EXPO_RAMP	Exponential Volume Ramp Enable
//				0x0 = Linear ramp over top 4 volume octaves
//				0x1 = Exponential ramp over full volume range
//				This bit only takes effect if VOL_RAMP_EN is 1.
// 3	DAC_MUTE_RIGHT	DAC Right Mute (default=1)
//				0x0 = Unmute
//				0x1 = Muted
//				If VOL_RAMP_EN = 1, this is a soft mute.
// 2	DAC_MUTE_LEFT	DAC Left Mute (default=1)
//				0x0 = Unmute
//				0x1 = Muted
//				If VOL_RAMP_EN = 1, this is a soft mute.
// 1	ADC_HPF_FREEZE	ADC High Pass Filter Freeze
//				0x0 = Normal operation
//				0x1 = Freeze the ADC high-pass filter offset register.  The
//				offset continues to be subtracted from the ADC data stream.
// 0	ADC_HPF_BYPASS	ADC High Pass Filter Bypass
//				0x0 = Normal operation
//				0x1 = Bypassed and offset not updated
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

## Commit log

2021-04-05 Reduce noise and power using OSC8M
    [main.cpp]
2021-04-05 Update board files
2021-04-12 Add WebUSB configuration tool
    [qtpy_m0.cfg]
2021-04-12 Fix filter bug
2021-04-19 Added USB power pulsing
2021-05-27 Change auto volume to default off
    [OE1 ParametricEQ.txt]
2021-07-09 Tweak volume and upload STL for case
    [prettygood_dsp_case.stl]
2022-04-18 Upload PCB and 3d model files
    [BOM_PCB_Prettygood_DSP_v1.1_2022-04-18.csv, PickAndPlace_PCB_Prettygood_DSP_v1.1_2022-04-18.csv, Prettygood DSP Case.f3d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]
